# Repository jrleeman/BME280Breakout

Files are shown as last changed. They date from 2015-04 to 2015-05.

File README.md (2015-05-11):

# BME280 Breakout

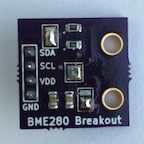
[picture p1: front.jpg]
Front of board

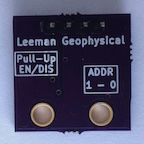
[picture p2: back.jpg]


## Purpose

Breakout board for the Bosch BME280 sensor. Selectable address and optional
pull-up resistors. This looks like a great little sensor and we wanted to
try it out!

## Purchasing

The dual channel instrumentation amplifier is available through Leeman
Geophysical by emailing [John R. Leeman](http://www.johnrleeman.com) at
<kd5wxb@gmail.com>.

## Project Information

This repository includes all design information, CAD files, PDF CAD output,
gerbers, etc.

Additional resources for this project include:

- [BME280 Datasheet](PDFs/bme280.pdf)
- [Bosch Drive Code Repo (from Bosch)](https://github.com/BoschSensortec/BME280_driver)
- [Example Arduino Code (from Embedded Adventures)](https://github.com/embeddedadventures/BME280)

## License

This product is licensed under the CERN Open Hardware License 1.2. The [full
license](cern_ohl_v_1_2.txt) is included in this repository.

## Hookup Guide

Connect the sensor to a 3.3 VDC supply and ground. Connect to the I2C bus of
your micro-controller or system. Note that this unit is NOT 5 VDC tolerant!
If you are using 5 VDC logic, please use a [level shifter](https://www.sparkfun.com/products/12009?gclid=CJTokbvrusUCFegF7AodUhAAqw) to prevent damage.

## Example Data

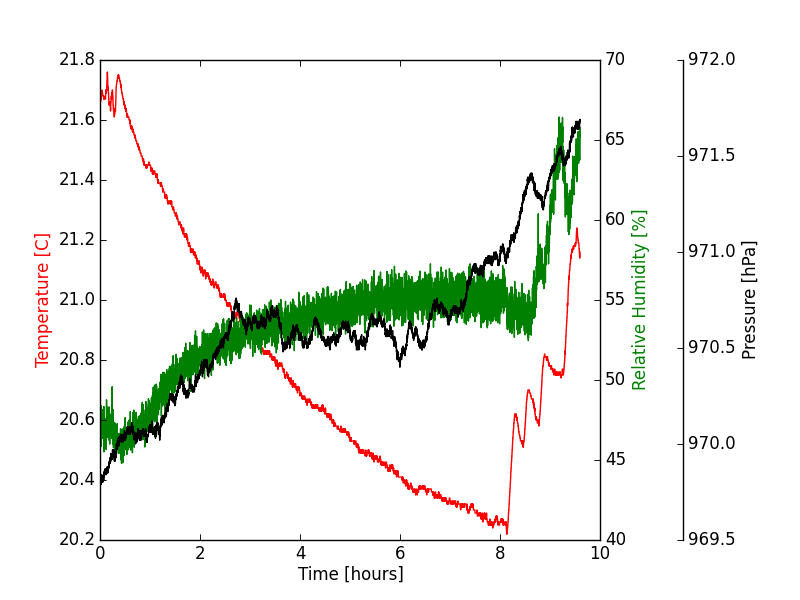
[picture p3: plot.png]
Example Plot


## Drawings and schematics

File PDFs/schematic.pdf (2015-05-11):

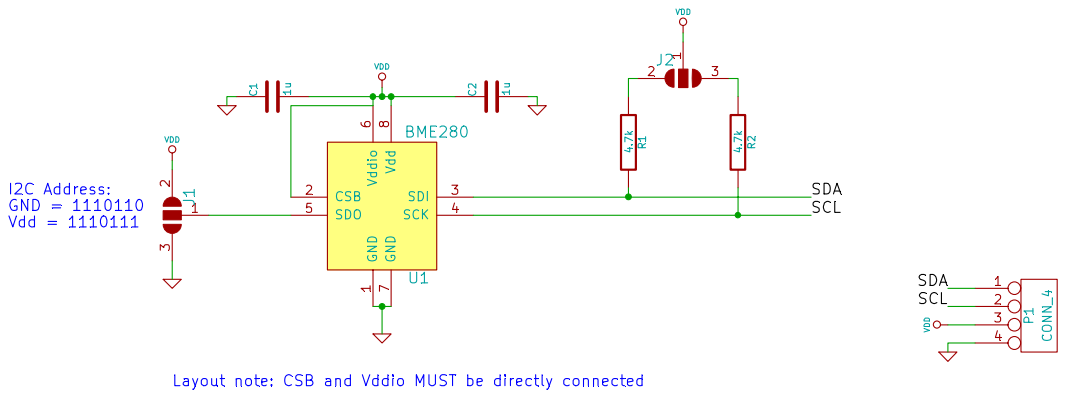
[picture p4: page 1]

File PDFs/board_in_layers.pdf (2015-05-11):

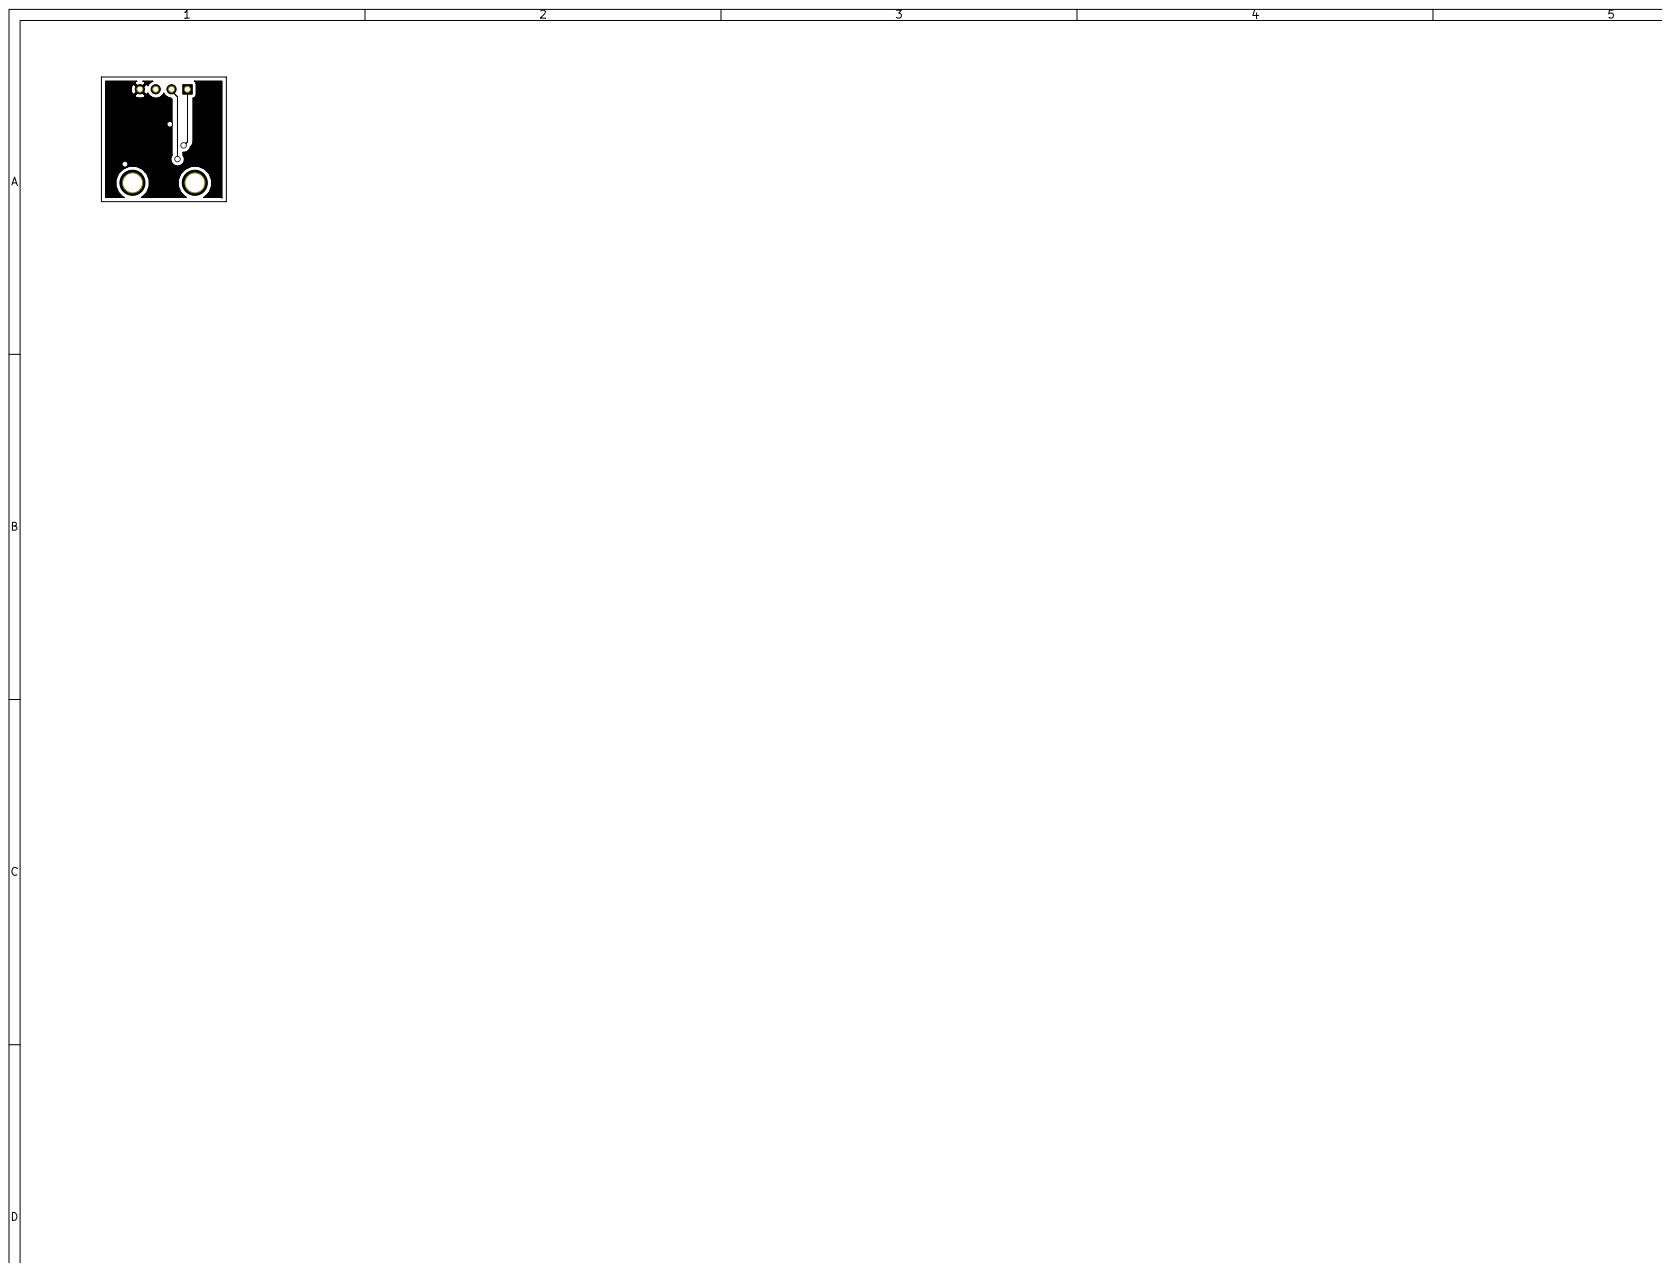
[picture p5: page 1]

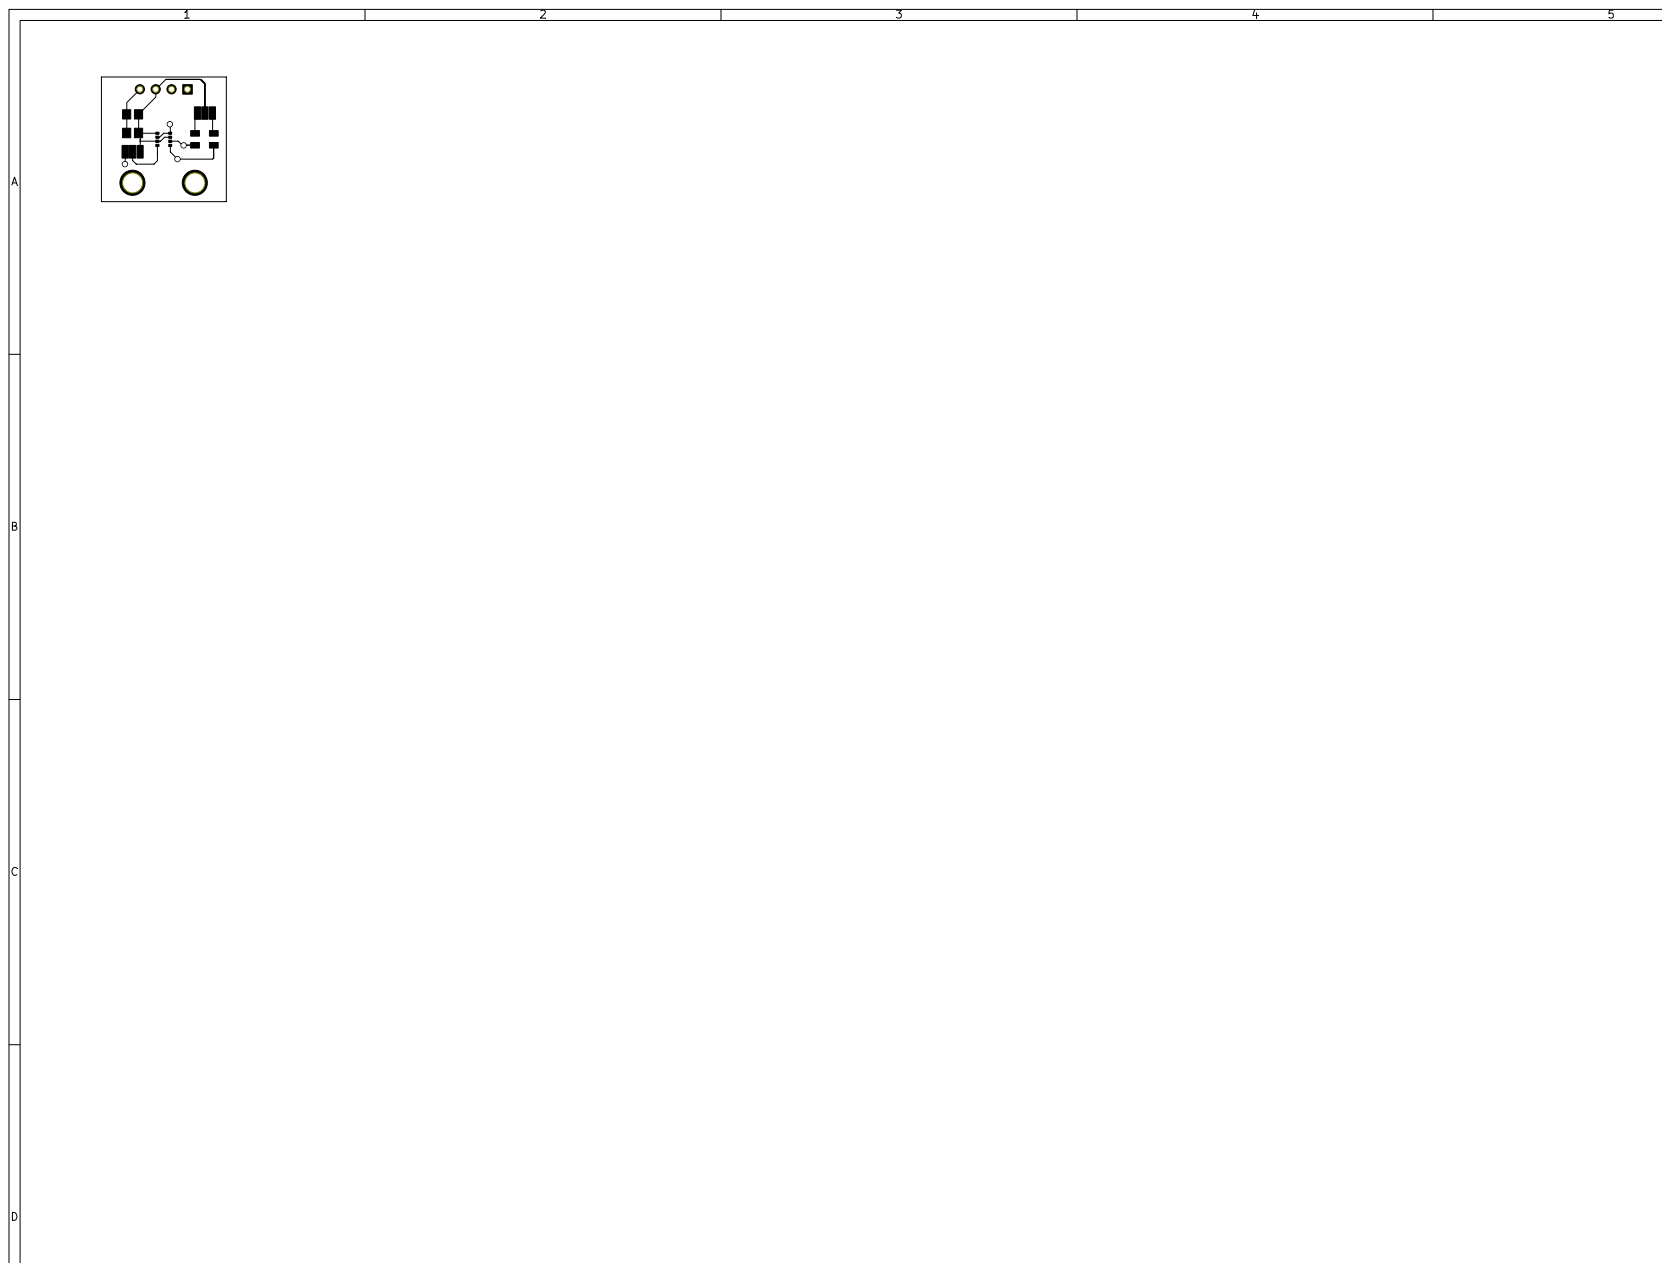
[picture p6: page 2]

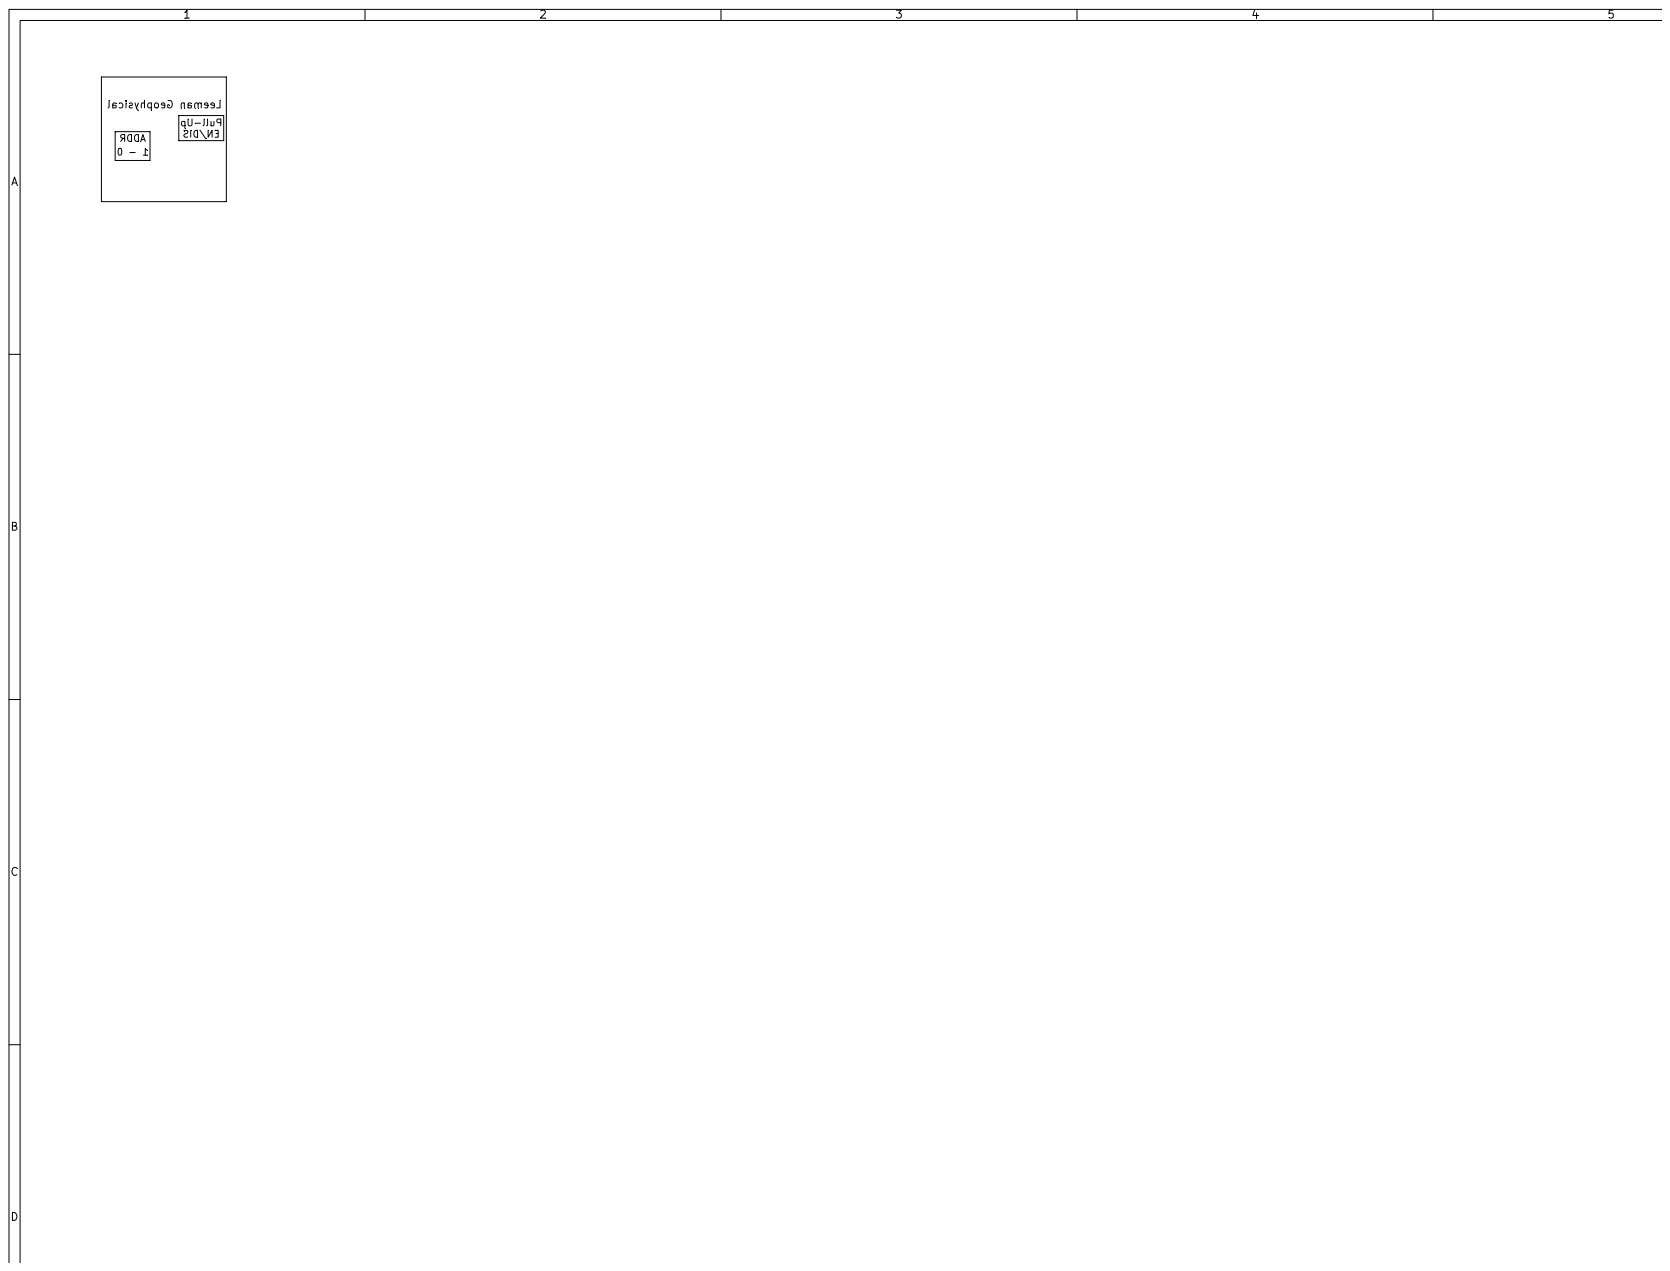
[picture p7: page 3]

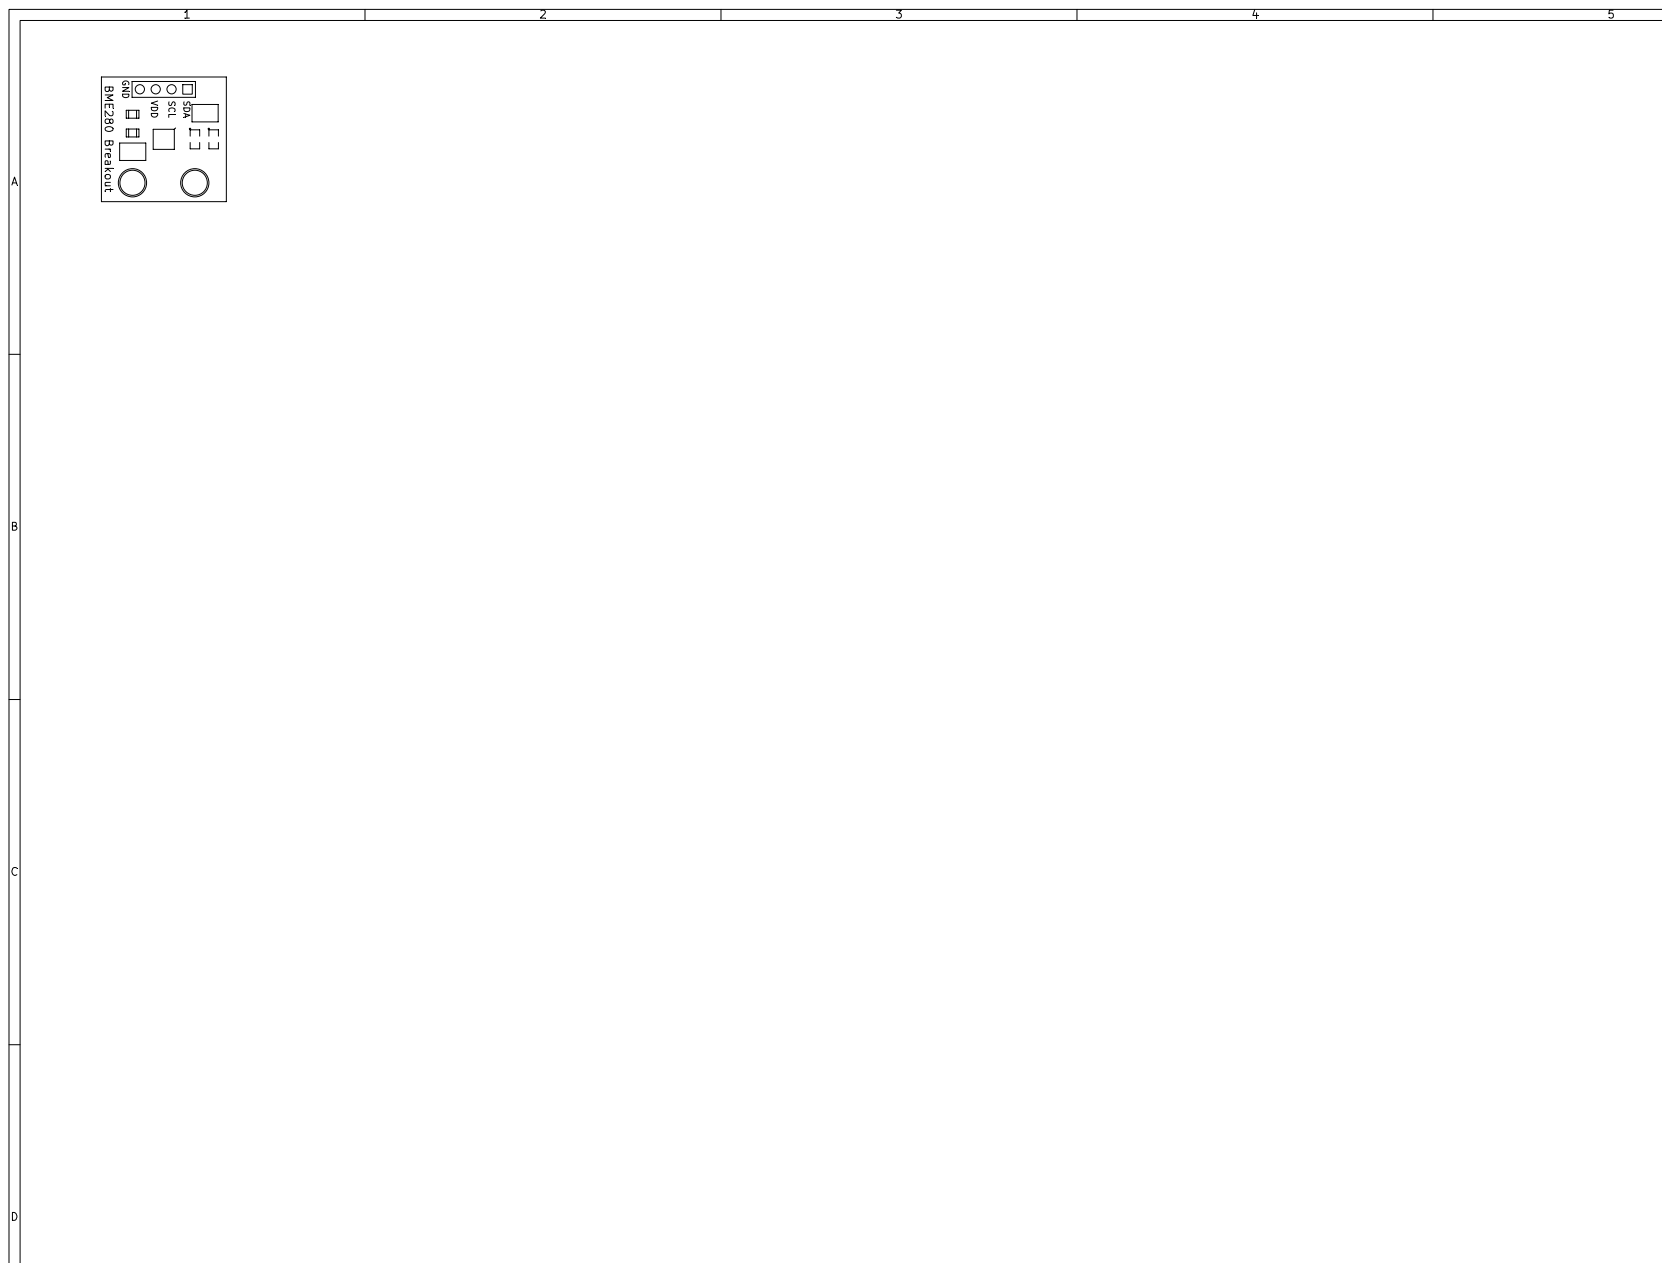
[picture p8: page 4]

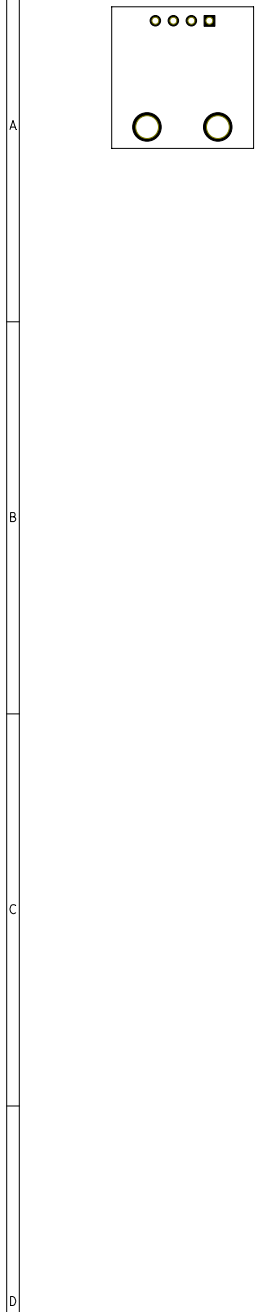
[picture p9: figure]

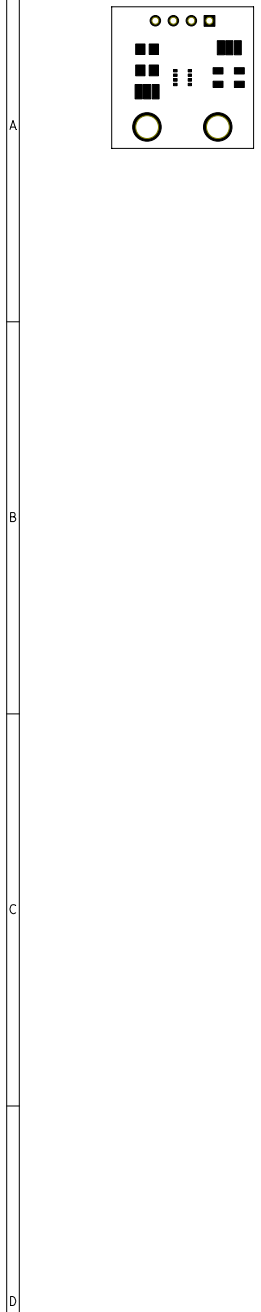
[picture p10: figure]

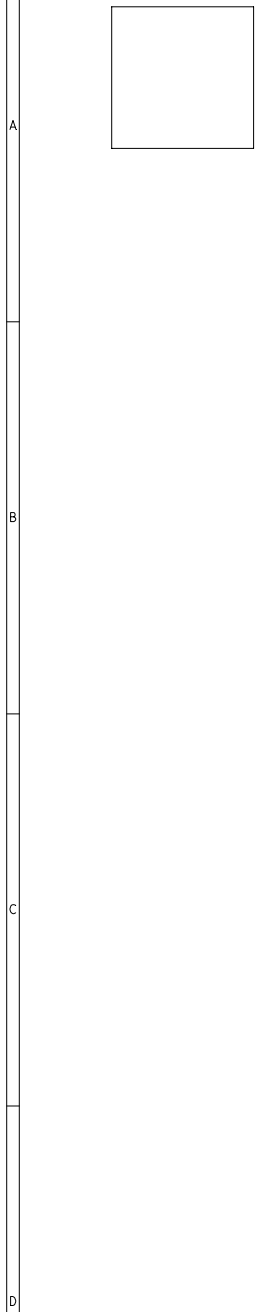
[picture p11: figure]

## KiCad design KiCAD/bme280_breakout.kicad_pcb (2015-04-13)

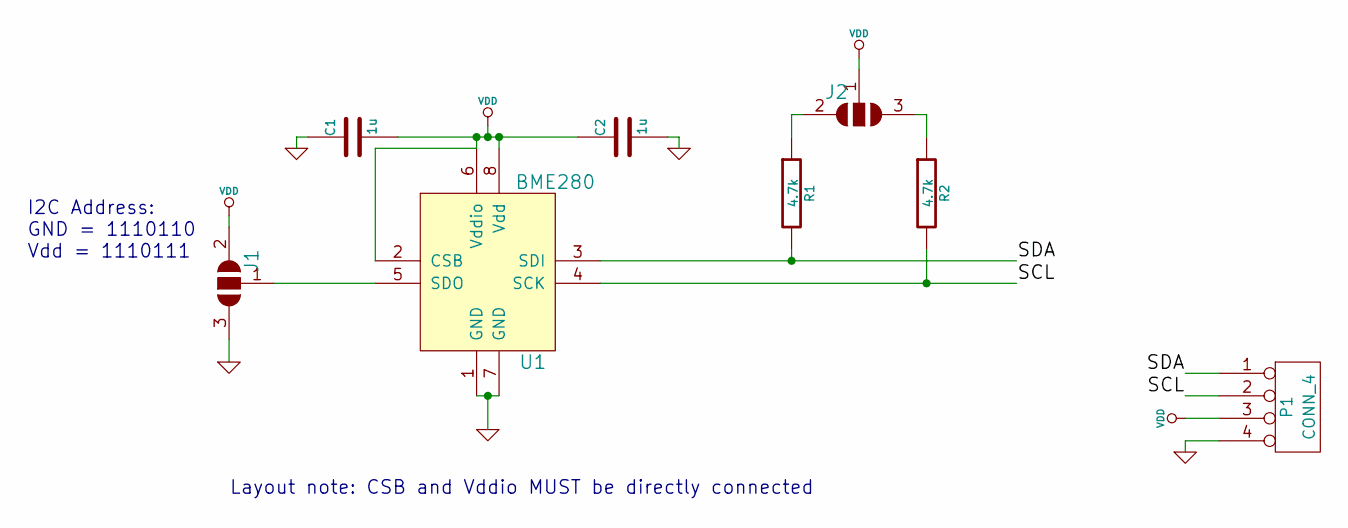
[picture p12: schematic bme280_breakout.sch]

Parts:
C1, C2: 1u
J1, J2: 2JUMPER
P1: CONN_4
R1, R2: 4.7k
U1: BME280

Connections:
/SCL: P1.2, R2.2, U1.4 (SCK)
/SDA: P1.1, R1.2, U1.3 (SDI)
GND: C1.1, C2.2, J1.3, P1.4, U1.1 (GND), U1.7 (GND)
unnamed: J2.2, R1.1
unnamed: J2.3, R2.1
unnamed: J1.1, U1.5 (SDO)
VDD: C1.2, C2.1, J1.2, J2.1, P1.3, U1.2 (CSB), U1.6 (Vddio), U1.8 (Vdd)

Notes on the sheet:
I2C Address: GND = 1110110 Vdd = 1110111
Layout note: CSB and Vddio MUST be directly connected

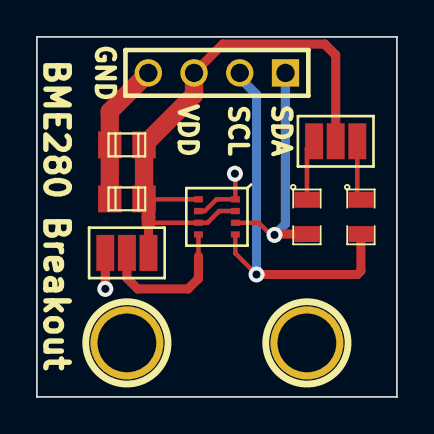
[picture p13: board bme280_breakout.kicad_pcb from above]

Board: 2 copper layers, 20.0 x 20.0 mm, 10 parts (0 on the bottom side), 7 nets.

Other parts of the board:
1PIN, 1PIN#2: P***; 1pin
